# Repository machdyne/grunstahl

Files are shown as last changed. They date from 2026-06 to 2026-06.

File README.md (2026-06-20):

# Grünstahl

Grünstahl is a USB-C device that provides access to 2 KB of Ferroelectric RAM over USB HID.

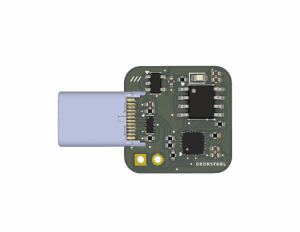
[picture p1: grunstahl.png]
Grünstahl


This repo contains schematics, firmware, software, documentation and a 3D printable case.

See the [product page](https://machdyne.com/product/grunstahl) for more information.

## Software

The 'hidxfer' utility or the WebHID-based hex/text editor can be used to access the data. There is also a native Android version of the hex/text editor.

## Building hidxfer (Linux)

```bash
cd sw
sudo apt install libhidapi-dev
make
```

On Linux you may need a udev rule to access the device without root.
Create /etc/udev/rules.d/99-grunstahl.rules:

  SUBSYSTEM=="hidraw", ATTRS{idVendor}=="1209", ATTRS{idProduct}=="d003", MODE="0666"

Then: sudo udevadm control --reload-rules && sudo udevadm trigger

## Usage

```bash
# Ping the device
./hidxfer --ping

# Read the entire 2 KB of FRAM to a file
./hidxfer -r backup.bin --bytes 2048

# Read 512 bytes starting at offset 1024
./hidxfer -r partial.bin --offset 1024 --bytes 512

# Write a file to FRAM starting at offset 0
./hidxfer -w data.txt

# Write a file to FRAM starting at offset 512
./hidxfer -w data.dat --offset 512
```

## Building the firmware

Updating the firmware requires a WCH-LinkE or other CH32V003 programmer. The SWIO header is labeled on the board.

```bash
cd fw
make        # builds grunstahl.bin
make flash  # flashes via WCH-LinkE (minichlink)
```

Requires: RISC-V GCC toolchain (riscv-none-embed-gcc or riscv32-unknown-elf-gcc).

## Protocol

```
255-byte HID feature report, report ID 0xaa.

Request (host to device):

  [0]    0xaa   magic
  [1]    0x00   request marker
  [2]    cmd    0x00=PING  0x01=READ  0x02=WRITE
  [3]    addr_lo  FRAM address low byte
  [4]    addr_hi  FRAM address high byte
  [5]    len    payload byte count (max 248)
  [6..]  data   write payload (WRITE only)

Response (device to host, polled until [1] == 0x01):

  [0]    0xaa   magic
  [1]    0x01   response marker
  [2]    status 0x01=ok  0x00=error
  [3..]  data   read payload (READ only)

Transfers larger than 248 bytes are automatically chunked by hidxfer.
```

## LLM-generated code

To the extent that there is LLM-generated code in this repo, it should be space indented. Any space indented code should be carefully audited and then converted to tabs (eventually).

## License

The contents of this repo are released under the [Lone Dynamics Open License](LICENSE.md) with the following exceptions:

  * The ch32fun library is MIT licensed.
  * The hidapi library is BSD licensed.

Note: You can use these designs for commercial purposes but we ask that instead of producing exact clones, that you either replace our trademarks and logos with your own or add your own next to ours.

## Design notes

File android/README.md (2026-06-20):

# Grünstahl — Android App

Native Android app for reading and writing the Grünstahl FRAM device over USB HID.
Features a hex editor and text editor matching the web version.

---

## Prerequisites

### Build machine
- **JDK 17+** — `java -version` to check
- **Android SDK with Build Tools 34** — install via Android Studio, or:
  ```bash
  # Download command-line tools from:
  # https://developer.android.com/tools/sdkmanager
  sdkmanager "build-tools;34.0.0" "platforms;android-34"
  ```
- Set `ANDROID_HOME` to your SDK location:
  ```bash
  export ANDROID_HOME=$HOME/Android/Sdk        # Android Studio on Linux
  export ANDROID_HOME=/usr/lib/android-sdk     # apt install android-sdk
  export ANDROID_HOME=$HOME/Library/Android/sdk # macOS
  ```
- **curl** or **wget** (to download Gradle on first run)

### Phone
- Android 8.0 (API 26) or later
- USB-C OTG cable or adapter

---

## Building

`build.sh` downloads Gradle 8.4 automatically on first run (~100 MB, cached in `~/.gradle`).

```bash
cd android/

# Build debug APK
./build.sh

# Build release APK (debug-signed, ready to sideload)
./build.sh release

# Build debug APK + install directly via adb
./build.sh install
```

Output:
- Debug:   `app/build/outputs/apk/debug/app-debug.apk`
- Release: `app/build/outputs/apk/release/app-release.apk`

---

## Installing (sideloading)

### Via adb (easiest)
```bash
# Enable on phone: Settings → Developer Options → USB Debugging
./build.sh install
# or manually:
adb install -r app/build/outputs/apk/debug/app-debug.apk
```

To enable Developer Options: Settings → About Phone → tap **Build Number** 7 times.

### Manual sideload (no PC needed after APK is on phone)
1. `./build.sh release`
2. Copy `app-release.apk` to your phone (USB, cloud, email, etc.)
3. On phone: Settings → Security → **Install unknown apps** → allow your file manager
4. Open the APK in the file manager → tap **Install**

---

## Connecting Grünstahl

1. Plug Grünstahl into your phone via USB-C OTG
2. The app launches automatically and asks for USB permission
3. Tap **OK** (tick "Always allow" to skip next time)
4. FRAM is read automatically on connect

---

## Project structure

```
android/
├── build.sh                          Build + install script
├── build.gradle                      Root Gradle config
├── settings.gradle
├── gradle.properties
└── app/
    ├── build.gradle
    └── src/main/
        ├── AndroidManifest.xml
        ├── java/com/grunstahl/fram/
        │   ├── GrunstahlHid.java     USB HID protocol (SET/GET_REPORT via controlTransfer)
        │   ├── HexGridView.java      Custom Canvas-based hex+ASCII grid
        │   └── MainActivity.java     UI, USB permission, tab switching
        ├── res/
        │   ├── layout/               activity_main.xml, dialog_edit_byte.xml
        │   ├── values/               strings, themes, colors
        │   ├── drawable/             shapes, cursor, icons
        │   └── xml/usb_device_filter.xml
        └── (generated by build: databinding, R.java)
```

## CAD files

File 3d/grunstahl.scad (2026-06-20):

/*
 * Grünstahl Case
 * Copyright (c) 2025 Lone Dynamics Corporation. All rights reserved.
 *
 * required hardware:
 *  - 1 x M2.5 x 10mm countersunk bolt
 *  - 1 x M2.5 nut
 *
 */

$fn = 30;

box_width = 19;
box_length = 26;
box_height = 10.5;
box_thickness = 2.0;

lid_thickness = 3;

cutout_width = 16.10;
cutout_length = 42.5;
cutout_height = 4.5;

cutout_usb_width = 8.4;

board_height = 0.8;

roundness = 1;

toladj = 0.25;

//translate([0,-5.25,0]) ssg_board(-0.25);
//translate([0,0,-0.5]) ssg_case();
translate([0,4.5,0]) ssg_endcap(0);

// m2.5 bolt
//translate([0,-11.5,-6.25]) color([1,0,0]) cylinder(d=2.5, h=12, $fn=36);

// m2.5 nut
//translate([0,-13.5,-6.55]) rotate(30) color([1,0,0]) cylinder(d=5.8, h=2.4, $fn=6);

module ssg_board(o)
{
	
	difference() {
		union() {
			translate([0,7,o])
				color([0.0,0.8,0.0]) cube([16, 16, 1.6], center=true);
			translate([0,20,o])
				color([0.9,0.9,0.9]) cube([8.2, 10, 2.4], center=true);
		}
		translate([0,-11,-10]) cylinder(d=4.2, h=100);
	}
	
}

module ssg_endcap(o)
{
		 	
	difference() {
        translate([0,-14.5,0]) cube([15.8,6,4.25], center=true);
		translate([0,-13.5,-4.25]) color([1,0,0]) cylinder(d=3.25, h=8, $fn=36);

	}
}

module ssg_case()
{
	
	difference() {
		
		minkowski() {
			cube([box_width-(roundness*2),box_length-(roundness*2),box_height-(roundness*2)],
				center=true);
			sphere(roundness);
		}
	
		translate([0,-10.5,(box_height-cutout_height)/2-2.5])
			cube([cutout_width+toladj,cutout_length,cutout_height], center=true);

		// USB cutout
		translate([0,10,0.25])
			cube([cutout_usb_width+toladj,10,2.4+toladj], center=true);

		// bolt hole
		translate([0,-9,-5]) cylinder(d=2.75+toladj, h=100, $fn=36);
		
		// nut cutout
		translate([0,-9,-5.75]) rotate(0) cylinder(d=6+toladj, h=2.5, $fn=6);
		
		// lid notch cutout
		translate([0,-9,4.25]) cylinder(d=5+toladj, h=100);

	}

}

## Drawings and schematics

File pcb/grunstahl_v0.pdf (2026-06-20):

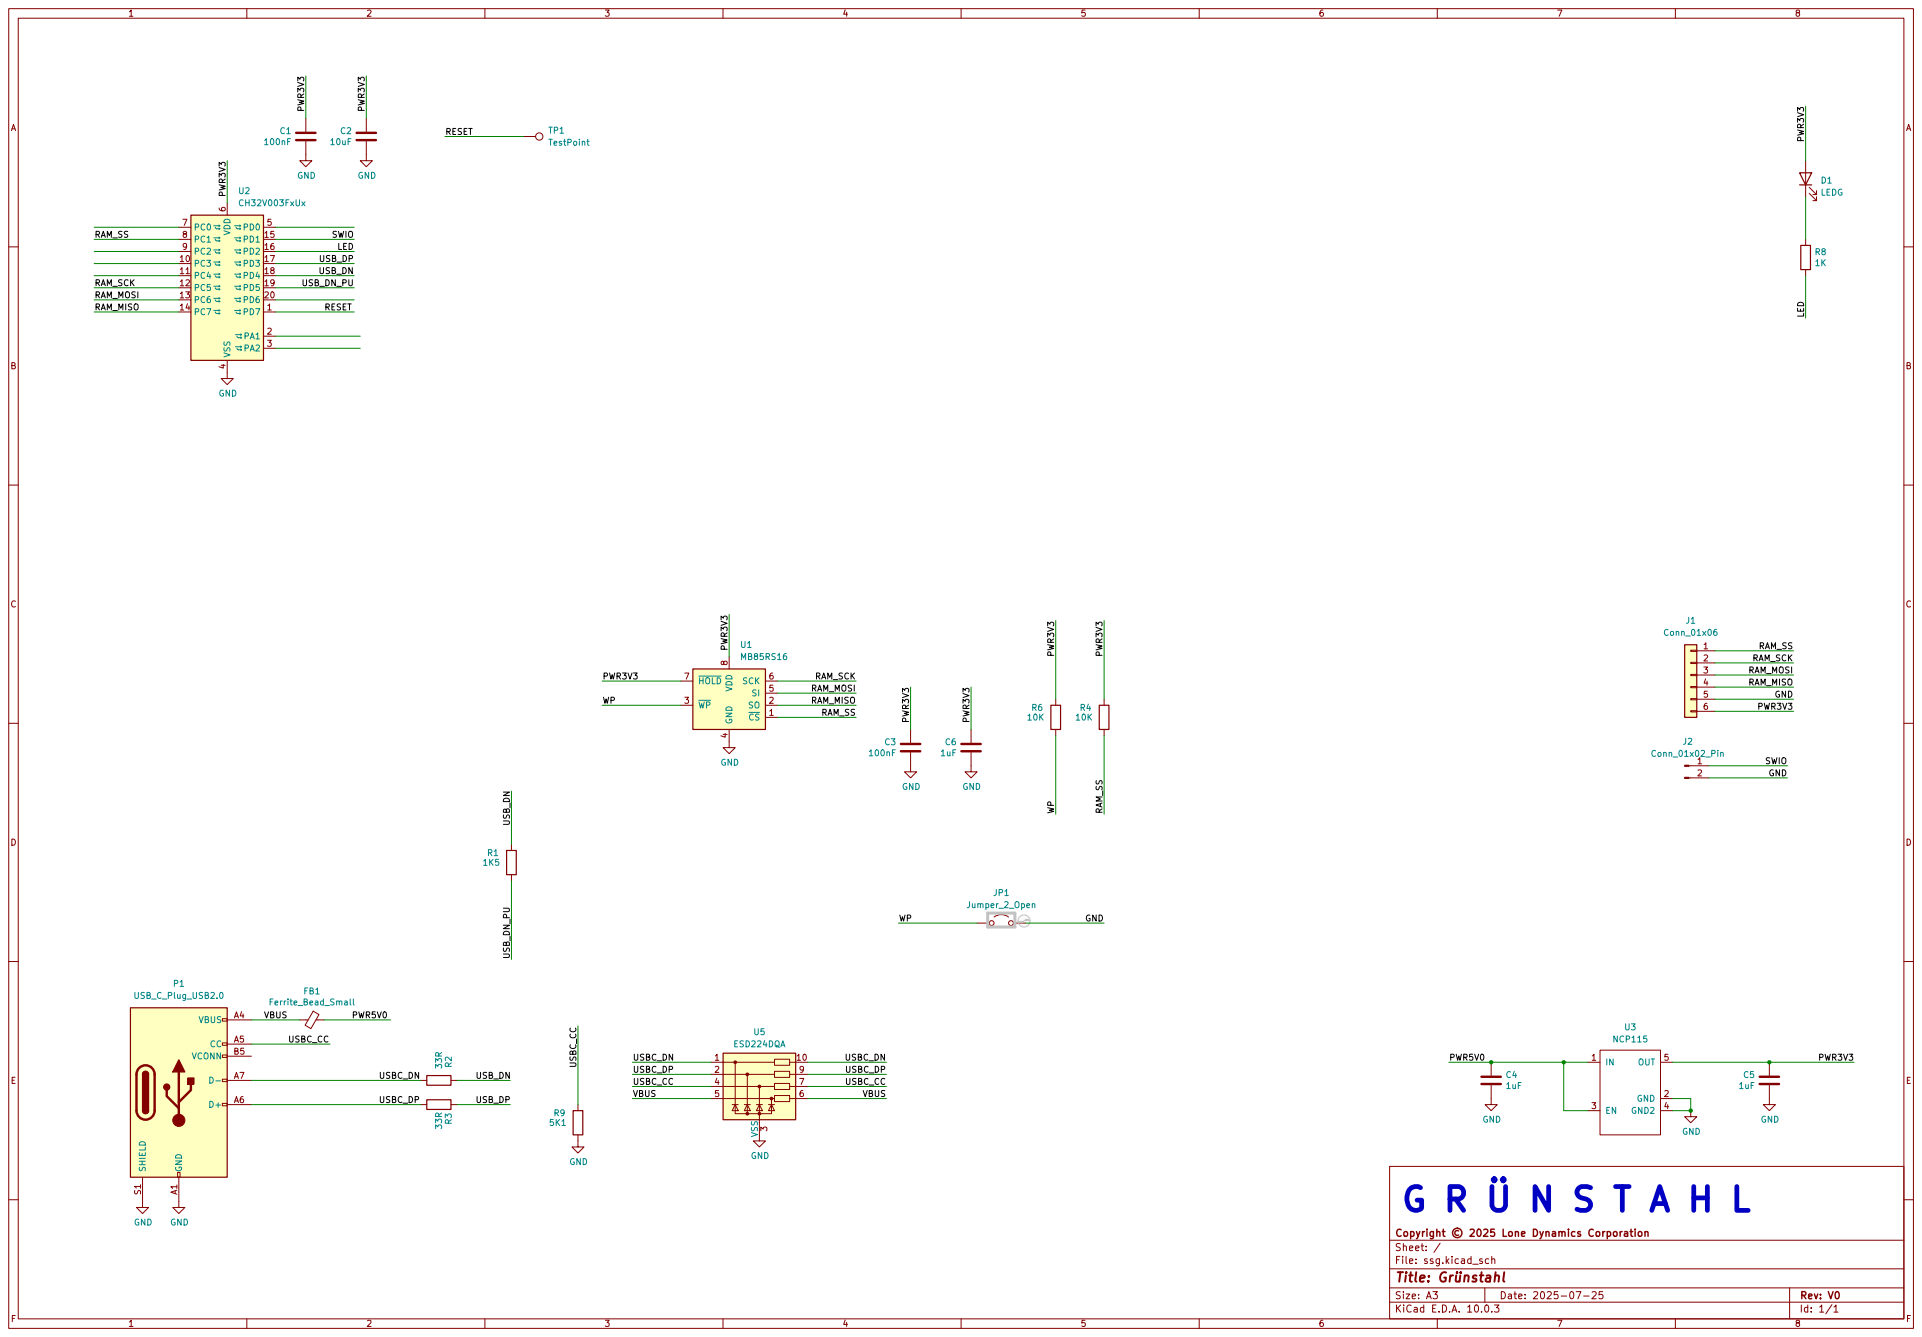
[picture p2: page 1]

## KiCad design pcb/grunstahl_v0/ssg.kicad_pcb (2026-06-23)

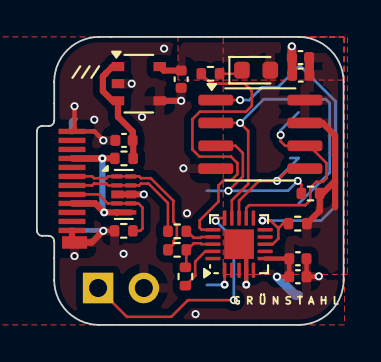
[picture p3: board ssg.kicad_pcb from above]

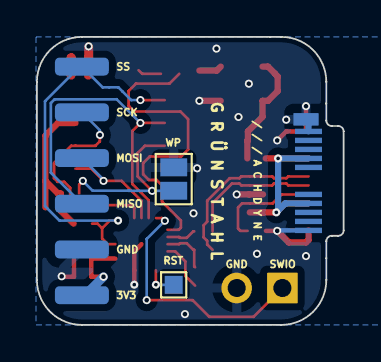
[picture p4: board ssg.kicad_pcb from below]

Board: 2 copper layers, 17.0 x 16.0 mm, 24 parts (3 on the bottom side), 19 nets.

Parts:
C1, C3: 100nF; C_0402_1005Metric
C2: 10uF; C_0402_1005Metric
C4, C5, C6: 1uF; C_0402_1005Metric
D1: LEDG; LED_0603_1608Metric
FB1: Ferrite_Bead_Small; R_0402_1005Metric
J1: Conn_01x06; LD-SMD-FEMALE-1x06
J2: Conn_01x02_Pin; PinHeader_1x02_P2.54mm_Vertical
JP1: Jumper_2_Open; SolderJumper-2_P1.3mm_Open_Pad1.0x1.5mm
P1: USB_C_Plug_USB2.0; USB_C_Plug_SHOUHAN_GTJB-040
R1: 1K5; R_0402_1005Metric
R2, R3: 33R; R_0402_1005Metric
R4, R6: 10K; R_0402_1005Metric
R8: 1K; R_0402_1005Metric
R9: 5K1; R_0402_1005Metric
TP1: TestPoint; TestPoint_Pad_1.0x1.0mm
U1: MB85RS16; SOIC-8_3.9x4.9mm_P1.27mm
U2: CH32V003FxUx; QFN-20-1EP_3x3mm_P0.4mm_EP1.65x1.65mm
U3: NCP115; TSOP-5_1.65x3.05mm_P0.95mm
U5: ESD224DQA; Diodes_UDFN-10_1.0x2.5mm_P0.5mm

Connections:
/LED: R8.2, U2.16 (PD2)
/PWR3V3: C1.1, C2.1, C3.1, C5.1, C6.1, D1.2 (A), J1.6, R4.2, R6.2, U1.7 (~HOLD), U1.8 (VDD), U2.6 (VDD), U3.5 (OUT)
/PWR5V0: C4.1, FB1.1, U3.1 (IN), U3.3 (EN)
/RAM_MISO: J1.4, U1.2 (SO), U2.14 (PC7)
/RAM_MOSI: J1.3, U1.5 (SI), U2.13 (PC6)
/RAM_SCK: J1.2, U1.6 (SCK), U2.12 (PC5)
/RAM_SS: J1.1, R4.1, U1.1 (~CS), U2.8 (PC1)
/RESET: TP1.1, U2.1 (PD7)
/SWIO: J2.1, U2.15 (PD1)
/USBC_CC: P1.A5 (CC), R9.2, U5.4, U5.7
/USBC_DN: P1.A7 (D-), R2.1, U5.1, U5.10
/USBC_DP: P1.A6 (D+), R3.1, U5.2, U5.9
/USB_DN: R1.2, R2.2, U2.18 (PD4)
/USB_DN_PU: R1.1, U2.19 (PD5)
/USB_DP: R3.2, U2.17 (PD3)
/VBUS: FB1.2, P1.A4 (VBUS), P1.A9 (VBUS), P1.B4 (VBUS), P1.B9 (VBUS), U5.5, U5.6
/WP: JP1.1 (A), R6.1, U1.3 (~WP)
GND: C1.2, C2.2, C3.2, C4.2, C5.2, C6.2, J1.5, J2.2, JP1.2 (B), P1.A1 (GND), P1.A12 (GND), P1.B1 (GND), P1.B12 (GND), P1.S1 (SHIELD), R9.1, U1.4 (GND), U2.4 (VSS), U2.21 (VSS), U3.2 (GND), U3.4 (GND2), U5.3 (VSS), U5.8 (VSS)
unnamed: D1.1 (K), R8.1

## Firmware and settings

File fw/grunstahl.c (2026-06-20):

/*
 * Grünstahl Firmware
 *
 * CH32V003 USB HID device providing read/write access to 2 KB of SPI F-RAM.
 * Based on Einszeit by Lone Dynamics Corporation / CNLohr.
 *
 * Protocol (255-byte HID feature report, report ID 0xaa):
 *
 *   Request  (host → device):
 *     [0]     0xaa        magic
 *     [1]     0x00        direction (request)
 *     [2]     cmd         GS_CMD_*
 *     [3..4]  addr_lo,hi  16-bit FRAM address (little-endian)
 *     [5]     len         payload length in bytes (max 248)
 *     [6..]   data        payload (write only)
 *
 *   Response (device → host):
 *     [0]     0xaa        magic
 *     [1]     0x01        direction (response)
 *     [2]     status      0x01 = ok, 0x00 = error
 *     [3..]   data        payload (read only)
 *
 * Commands:
 *   GS_CMD_PING   0x00   — returns ok, no data
 *   GS_CMD_READ   0x01   — read len bytes from addr → response[3..]
 *   GS_CMD_WRITE  0x02   — write len bytes at addr from request[6..]
 *
 * Pinout:
 *   PC1  FRAM_SS   (SPI chip select, active-low)
 *   PC5  FRAM_SCK  (SPI clock)
 *   PC6  FRAM_MOSI (SPI data out)
 *   PC7  FRAM_MISO (SPI data in)
 *   PD2  LED       (activity, active-high)
 *   PD3  USB D+
 *   PD4  USB D-    (1.5k pull-up via PD5 → Low-Speed)
 *   PD5  USB PU
 */

#include <stdio.h>
#include <string.h>
#include <stdint.h>
#include "rv003usb.h"
#include "ch32fun.h"

/* ── Protocol ───────────────────────────────────────────────────────────── */

#define GS_CMD_PING   0x00
#define GS_CMD_READ   0x01
#define GS_CMD_WRITE  0x02

#define GS_MAX_PAYLOAD 248   /* 255 - 7 header bytes */
#define FRAM_SIZE      2048

/* ── Pins ───────────────────────────────────────────────────────────────── */

#define FRAM_SS_PIN   1   /* PC1 */
#define FRAM_SCK_PIN  5   /* PC5 */
#define FRAM_MOSI_PIN 6   /* PC6 */
#define FRAM_MISO_PIN 7   /* PC7 */
#define LED_PIN       2   /* PD2 */

/* ── SPI helpers ────────────────────────────────────────────────────────── */

static inline void ss_low(void)   { GPIOC->BSHR = (1u << (16 + FRAM_SS_PIN)); }
static inline void ss_high(void)  { GPIOC->BSHR = (1u << FRAM_SS_PIN); }
static inline void sck_low(void)  { GPIOC->BSHR = (1u << (16 + FRAM_SCK_PIN)); }
static inline void sck_high(void) { GPIOC->BSHR = (1u << FRAM_SCK_PIN); }
static inline void mosi_set(int b) {
    if (b) GPIOC->BSHR = (1u << FRAM_MOSI_PIN);
    else   GPIOC->BSHR = (1u << (16 + FRAM_MOSI_PIN));
}
static inline int miso_read(void) { return (GPIOC->INDR >> FRAM_MISO_PIN) & 1; }

static uint8_t spi_xfer(uint8_t tx)
{
    uint8_t rx = 0;
    for (int i = 7; i >= 0; i--) {
        mosi_set((tx >> i) & 1);
        sck_high();
        rx = (uint8_t)((rx << 1) | miso_read());
        sck_low();
    }
    return rx;
}

/* ── FRAM driver ────────────────────────────────────────────────────────── */

#define FRAM_OP_WREN  0x06
#define FRAM_OP_READ  0x03
#define FRAM_OP_WRITE 0x02

static void fram_init(void)
{
    RCC->APB2PCENR |= RCC_APB2Periph_GPIOC;

    uint32_t crl = GPIOC->CFGLR;
    /* PC1 SS   output PP 10MHz (bits  7:4) */
    crl &= ~(0xFu <<  4); crl |= (0x1u <<  4);
    /* PC5 SCK  output PP 10MHz (bits 23:20) */
    crl &= ~(0xFu << 20); crl |= (0x1u << 20);
    /* PC6 MOSI output PP 10MHz (bits 27:24) */
    crl &= ~(0xFu << 24); crl |= (0x1u << 24);
    /* PC7 MISO input floating (bits 31:28) */
    crl &= ~(0xFu << 28); crl |= (0x4u << 28);
    GPIOC->CFGLR = crl;

    ss_high();
    sck_low();
}

static void fram_read(uint16_t addr, uint8_t *buf, uint16_t len)
{
    ss_low();
    spi_xfer(FRAM_OP_READ);
    spi_xfer((uint8_t)(addr >> 8));
    spi_xfer((uint8_t)(addr & 0xFF));
    for (uint16_t i = 0; i < len; i++)
        buf[i] = spi_xfer(0x00);
    ss_high();
}

static void fram_write(uint16_t addr, const uint8_t *buf, uint16_t len)
{
    /* WREN — latch clears after each /CS rising edge */
    ss_low(); spi_xfer(FRAM_OP_WREN); ss_high();

    ss_low();
    spi_xfer(FRAM_OP_WRITE);
    spi_xfer((uint8_t)(addr >> 8));
    spi_xfer((uint8_t)(addr & 0xFF));
    for (uint16_t i = 0; i < len; i++)
        spi_xfer(buf[i]);
    ss_high();
}

/* ── LED ────────────────────────────────────────────────────────────────── */

static void led_init(void)
{
    RCC->APB2PCENR |= RCC_APB2Periph_GPIOD;
    GPIOD->CFGLR &= ~(0xFu << (4 * LED_PIN));
    GPIOD->CFGLR |=  (GPIO_Speed_10MHz | GPIO_CNF_OUT_PP) << (4 * LED_PIN);
    GPIOD->BSHR = (1u << (16 + LED_PIN)); /* off */
}

static inline void led_on(void)  { GPIOD->BSHR = (1u << LED_PIN); }
static inline void led_off(void) { GPIOD->BSHR = (1u << (16 + LED_PIN)); }

/* ── Shared HID scratch buffer (same pattern as Einszeit) ───────────────── */

uint8_t scratch[255];
volatile uint8_t start = 0;

/* ── Command handler ────────────────────────────────────────────────────── */

static void handle_command(void)
{
    uint8_t cmd    = scratch[2];
    uint16_t addr  = (uint16_t)(scratch[3] | (scratch[4] << 8));
    uint8_t  len   = scratch[5];

    /* Clamp len to safe maximum and FRAM bounds */
    if (len > GS_MAX_PAYLOAD) len = GS_MAX_PAYLOAD;
    if ((uint32_t)addr + len > FRAM_SIZE) {
        scratch[2] = 0x00; /* error */
        return;
    }

    led_on();

    switch (cmd) {

        case GS_CMD_PING:
            scratch[2] = 0x01;
            break;

        case GS_CMD_READ:
            fram_read(addr, &scratch[3], len);
            scratch[2] = 0x01;
            break;

        case GS_CMD_WRITE:
            fram_write(addr, &scratch[6], len);
            scratch[2] = 0x01;
            break;

        default:
            scratch[2] = 0x00; /* unknown command */
            break;
    }

    led_off();
}

/* ── Main ───────────────────────────────────────────────────────────────── */

int main(void)
{
    SystemInit();
    Delay_Ms(1); /* ensure USB re-enumeration after reset */

    led_init();
    fram_init();

    usb_setup();

    while (1) {
#if RV003USB_EVENT_DEBUGGING
        uint32_t *ue = GetUEvent();
        if (ue) printf("%lu %lx %lx %lx\n", ue[0], ue[1], ue[2], ue[3]);
#endif
        if (start && scratch[0] == 0xaa && scratch[1] == 0x00) {
            handle_command();
            scratch[1] = 0x01; /* mark as response */
            start = 0;
        }
    }
}

/* ── rv003usb HID callbacks (identical pattern to Einszeit) ─────────────── */

void usb_handle_user_in_request(struct usb_endpoint *e, uint8_t *scratchpad,
                                int endp, uint32_t sendtok,
                                struct rv003usb_internal *ist)
{
    if (endp) usb_send_empty(sendtok);
}

void usb_handle_user_data(struct usb_endpoint *e, int current_endpoint,
                          uint8_t *data, int len,
                          struct rv003usb_internal *ist)
{
    int offset = e->count << 3;
    int torx   = e->max_len - offset;
    if (torx > len) torx = len;
    if (torx > 0) {
        memcpy(scratch + offset, data, torx);
        e->count++;
        if ((e->count << 3) >= e->max_len)
            start = e->max_len;
    }
}

void usb_handle_hid_get_report_start(struct usb_endpoint *e, int reqLen,
                                     uint32_t lValueLSBIndexMSB)
{
    if (reqLen > (int)sizeof(scratch)) reqLen = sizeof(scratch);
    e->opaque  = scratch;
    e->max_len = reqLen;
}

void usb_handle_hid_set_report_start(struct usb_endpoint *e, int reqLen,
                                     uint32_t lValueLSBIndexMSB)
{
    if (reqLen > (int)sizeof(scratch)) reqLen = sizeof(scratch);
    e->max_len = reqLen;
}

void usb_handle_other_control_message(struct usb_endpoint *e,
                                      struct usb_urb *s,
                                      struct rv003usb_internal *ist)
{
    LogUEvent(SysTick->CNT, s->wRequestTypeLSBRequestMSB,
              s->lValueLSBIndexMSB, s->wLength);
}

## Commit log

2026-06-20 add enclosure
    [grunstahl.scad]
2026-06-23 add kicad files
    [ssg.kicad_pcb, ssg.kicad_sch]
2026-06-26 update pid
2026-09-02 ffix android bug; some devices wouldn't connect

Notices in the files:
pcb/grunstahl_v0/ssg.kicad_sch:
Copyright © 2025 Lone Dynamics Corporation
